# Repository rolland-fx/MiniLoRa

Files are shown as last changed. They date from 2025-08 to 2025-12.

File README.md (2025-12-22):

# Introduction

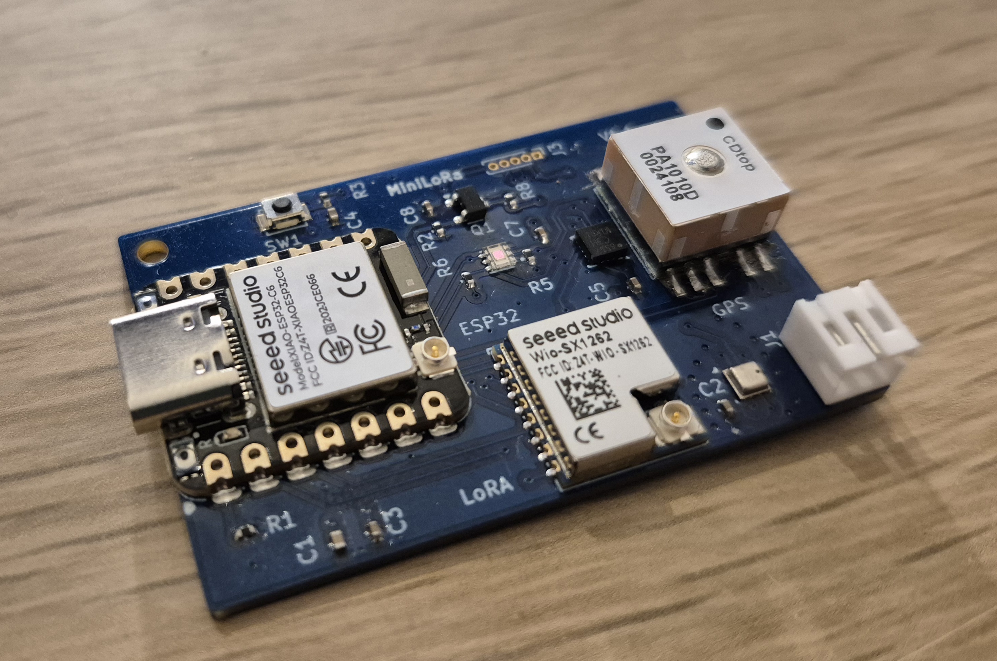
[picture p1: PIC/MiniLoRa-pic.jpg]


---
<!---
Discord server dedicated to this project :
<a href="https://discord.gg/ZdWrauP4Yt"><img alt="Discord" src="https://img.shields.io/badge/-Join-lightblue?logo=discord"></a>
---
-->
## Table of Contents

- [✨ What's MiniLoRa?](#-whats-MiniLoRa)
- [⚙️ Hardware Overview](#-hardware-overview)
- [💾 Software Overview](#-software-overview)
- [🚀To Do and Next Steps](#-to-do-and-next-steps)

## ✨ What's MiniLoRa?

Small size multi-purpose **ESP32-C6** board with **LoRa** and **2.4 GHz** connectivity.

**Main focus**

* Low power consumption for long battery life
* Multiple wireless connectivity
* Sensors packed
* Small size

### Features

* ESP32-C6 -> <a href="./DOC/Datasheets/esp32-c6.pdf">XIAO-ESP32C6</a>
  * 32 bits RISC-V Main processor : 160 MHz
  * 32 bits RISC-V Low power processor : 20 MHz
  * 512 KB RAM
  * 4 MB FLASH
  * RTC
  * Wi-Fi 6 (2.4 GHz)
  * Bluetooth 5 (BLE)
  * Zigbee / Matter / Thread (802.15.4)
  * All 2.4 GHz radios : Internal or external antenna switch via GPIO
* LoRa modem -> <a href="./DOC/Datasheets/Wio-SX1262_Module.pdf">WIO-SX1262</a>
  * LoRaWan capable
  * External Antenna
* GNSS with integrated antenna and PPS -> <a href="./DOC/Datasheets/CD-PA1010D.pdf">CD-PA1010D</a>
* Temperature, humidity and pressure sensor -> <a href="./DOC/Datasheets/bst-bme280-ds002.pdf">BME280</a>
* Luminosity sensor -> <a href="./DOC/Datasheets/opt3001.pdf">OPT3001</a>
* 3-axis accelerometer -> <a href="./DOC/Datasheets/lis3dh.pdf">LIS3DH</a>
* External connector with : Power, I2C and 1 GPIO
* 1 user accessible LED
* 1 user accessible button
* Voltage reading of the battery
* Integrated BMS and JST connector

## ⚙️ Hardware Overview

**PCB dimension**

| D| mm|
| --- | --- |
| L | 50 |
| W | 32 |
| H | 12,5* |

* including GNSS module and JST connector

**PCB Info**

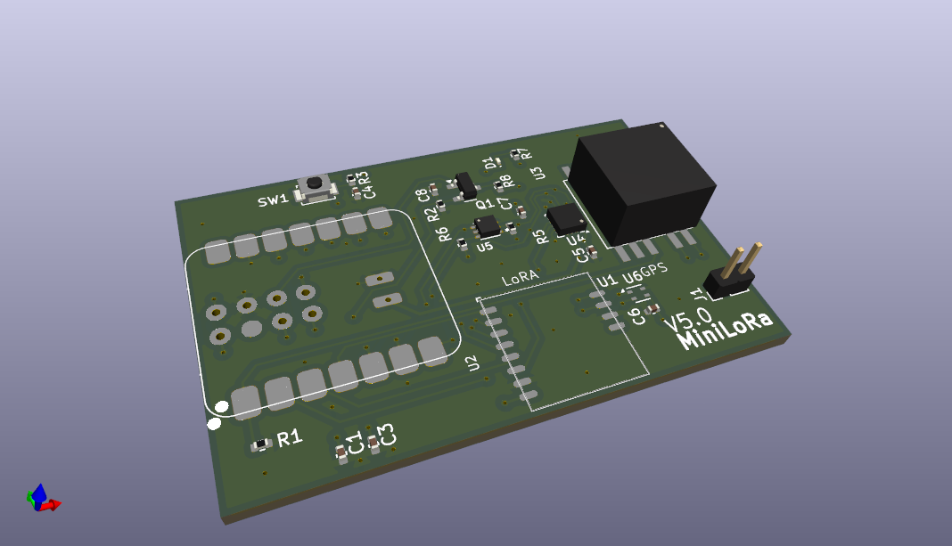
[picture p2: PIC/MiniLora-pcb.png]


Design with Kicad 9.0

* Full schematic and design can be found under **HW\PCB**
* Production files for the current batch are also included
* Libraries used can be found under **HW\PCB\lib**
* PDF can be found under : **DOC\Schematics**

**Enclosure Info**

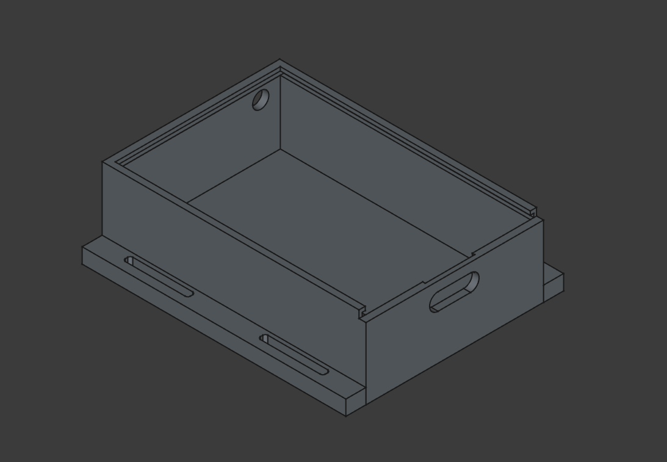
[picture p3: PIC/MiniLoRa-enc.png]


Design with FreeCad 1.0

* Very basic and not finished
* Can be 3D printed with basic HW
* Should be improved in the future
* Thought to be attached to backpack

## 💾 Software Overview

I2C adresses of sensors

| Sensor| ADD|
| --- | --- |
| GNSS | 0x10 |
| ACC | 0x18 |
| TEMP | 0x76 |
| LUM | 0x47 |

GPIO Mapping

| GPIO| Usage| Usable in SW ? | ADC ? | LP GPIO ?| Note|
| --- | --- | --- | --- | --- |---|
| 0 | WakeUp GNSS | X | X | X | |
| 1 | LoRa Busy + ACC Interupt | X | X | X | Mixed both signal|
| 2 | LoRa Reset | X | X | X | |
| 3 | 2.4 GHz switch EN | X | X | X | |
| 4 | Bat. Reading En. + External GPIO  | X | X | X | Use to activate External GPIO and EN. Bat reading |
| 5 | Bat. Analog  | X |X | X | Read Vbat/2 when active |
| 6 | PPS | X | X | X | |
| 7 | User Button | X |  | X | |
| 8 | Not available on XIAO ESP32C6 Module| | | | Strapping pin, HW pull-UP |
| 9 | Boot| | | | |
| 10-11 | N/A on ESP32C6 with Inc. FLASH| | | | |
| 12 | USB DN| | | | Used for serial and prog. |
| 13 | USB DP| | | | Used for serial and prog. |
| 14 | 2.4GHz switch Select| X | | | |
| 15 | Orange LED| X | | | |
| 16 | LoRa DIO1 | X | | | |
| 17 | LoRa SPI Select | X | | | |
| 18 | SPI MOSI | X | | | |
| 19 | SPI SCK | X | | | |
| 20 | SPI MISO | X | | | |
| 21 | LoRa RF Switch | X | | |Actually useless. GPIO will be reused in next version |
| 22 | I2C SDA | X | | | |
| 23 | i2C SPI | X | | | |
| 24 - 30| Internal SPI FLASH | | | | Not exposed|

External Connector Mapping

1 is defined as the squared one, closest to J3 marking 

| Pin | Usage|
| --- | --- |
| 1 | GND |
| 2 | SCL |
| 3 | SDA |
| 4 | VCC |
| 5 | GPIO6 |

## 🚀To Do and Next Steps

Here are the idea for the next improvement and developpement :

### Software

* Create a first full version in Arduino : Mostly done.
* Architecture
  * Create a core with FreeRTOS or Zephyr
  * Create drivers for all HW
  * File system for sys. files and data files
  * Init routine and deep sleep related routine
  * "1 Button, 1 LED" interface
* Possible SW usage
  * Very long battery life LoRaWAN tracker (all sensors) + reverse channel
  * NTP (GPS with PPS) Wi-Fi server
  * Indoor Zigbee / Wi-Fi / BLE sensor (all but GPS)  + reverse channel
  * Outdoor environmental sensor (all sensors)  + reverse channel
  * Outdoor offline sensor logging (Storage to FLASH)
  * Anti-theft device (interupt on Acc + all Radios)
* Other related SW
  * BLE App for configuration
  * USB-C (serial) App for configuration  

### Hardware

* Size can me optimized
* GNSS module with external flat antenna
* Replace JST 2.0 by PH1.25 for the Battery connector
* Replace External connector by 1.25mm pitch connector
  * GND + VCC
  * I2C
  * 2 GPIOs (probably one shared with another thing and one dedicated)   
* Better thermal isolation for BME280
* Sx1262 RF_SWITCH (GPIO 21) is not needed and can be used for something else.
* Replace XIAO module par self-made ESP32C6 module -> BIG WORK
  * Use ESP32-C6FH8 -> 8 MB of FLASH
  * Remove 2.4 GHz switch to get back 2 GPIO
  * GPIO 8 : could be used for an OUTPUT (to avoid strapping issue)
  * Replace BMS for solar cell use and faster charge : CN3165 or keeping the same, but change the cabling
  * Chose either chip antenna or external connector

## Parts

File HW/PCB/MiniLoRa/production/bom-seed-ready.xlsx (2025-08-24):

Designator | MPN/Seeed SKU | Qty | Link
D1 | 304090045 | 1
C5,C3,C7,C6,C8 | 302010004 | 5
SW1 | 311020679 | 1
R3,R5,R6,R1 | 301010004 | 4
U2 | 113991254 | 1
R8,R2 | 301010033 | 2
C4,C1 | 302010053 | 2
Q1 | 305031501 | 1
U5 | 314020321 | 1
R7 | 301010001 | 1
U6 | 314010719 | 1
U1 | 114993390 | 1 | https://www.seeedstudio.com/Wio-SX1262-Wireless-Module-p-5981.html
U4 | 314080105 | 1

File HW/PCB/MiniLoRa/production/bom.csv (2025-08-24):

Designator | Footprint | Quantity | Value | LCSC Part #
C1 | 0402 | 1 | 10u | C15525
C2 | 0402 | 1 | 1u | C14445
C3, C6, C7, C8 | 0402 | 4 | 0.1u | C1546
C4, C5 | 0402 | 2 | 10uF | C15525
D1, D2 | 0805 | 2 | LED | C2293
J1 | PinHeader_1x02_P2.00mm_Vertical | 1 | Conn_01x02
Q1 | SOT-23 | 1 | AO3400A | C20917
R1, R3, R5, R6, R9 | 0402 | 5 | 10K | C25744
R2, R8 | 0402 | 2 | 100k | C60491
R4, R7 | 0402 | 2 | 1.5k | C25867
SW1, SW2 | SW_SPST_B3U-1000P-B | 2 | SW_Push | C498294
U1 | wio-sx1262 | 1 | Wio-SX1262
U2 | XIAO-ESP32C6-SMD | 1 | XIAO-ESP32-S3-SMD
U3 | CDTop_MT3333_PA1010D | 1 | PA1010D
U5 | SON65P200X200X65-7N | 1 | OPT3001DNPR | C90462
U6 | Sensirion_DFN-4_1.5x1.5mm_P0.8mm_SHT4x_NoCentralPad | 1 | SHT4x | C7461852

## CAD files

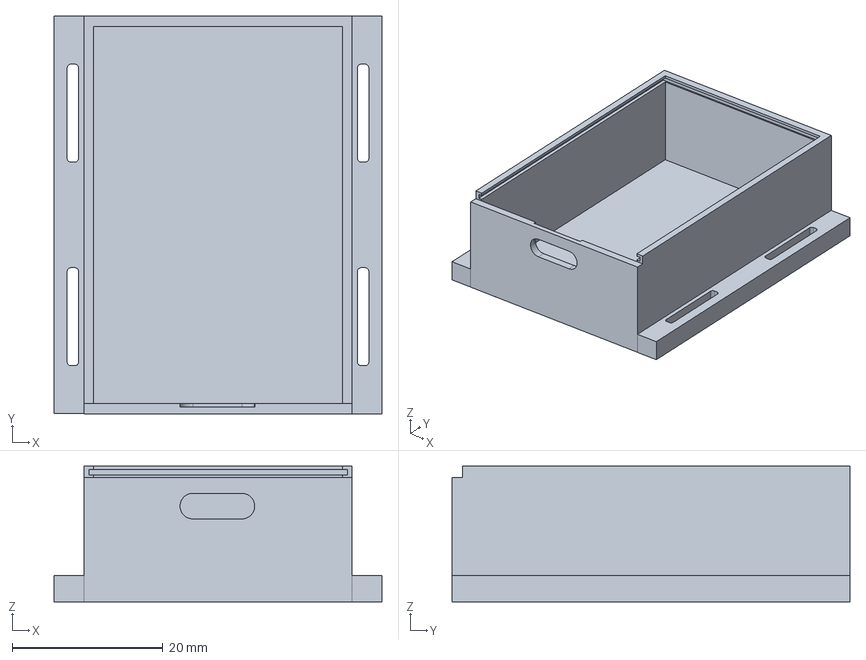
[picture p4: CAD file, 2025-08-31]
HW/Enclosure/MiniLoRa-Box.FCStd
43.5 x 52.8 x 18.0 mm

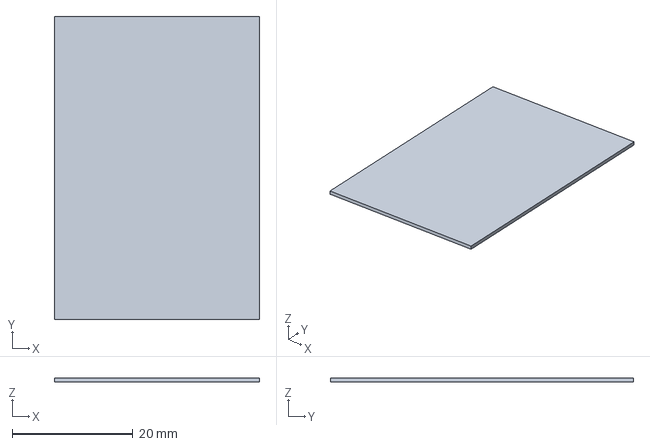
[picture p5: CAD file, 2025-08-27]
HW/Enclosure/MiniLoRa-Box-Top.3mf
34.0 x 50.2 x 0.7 mm

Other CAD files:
HW/Enclosure/MiniLoRa-Box-Body.3mf
HW/OLD-BETA5/Enclosure/MiniLoRa-Box-Body.3mf

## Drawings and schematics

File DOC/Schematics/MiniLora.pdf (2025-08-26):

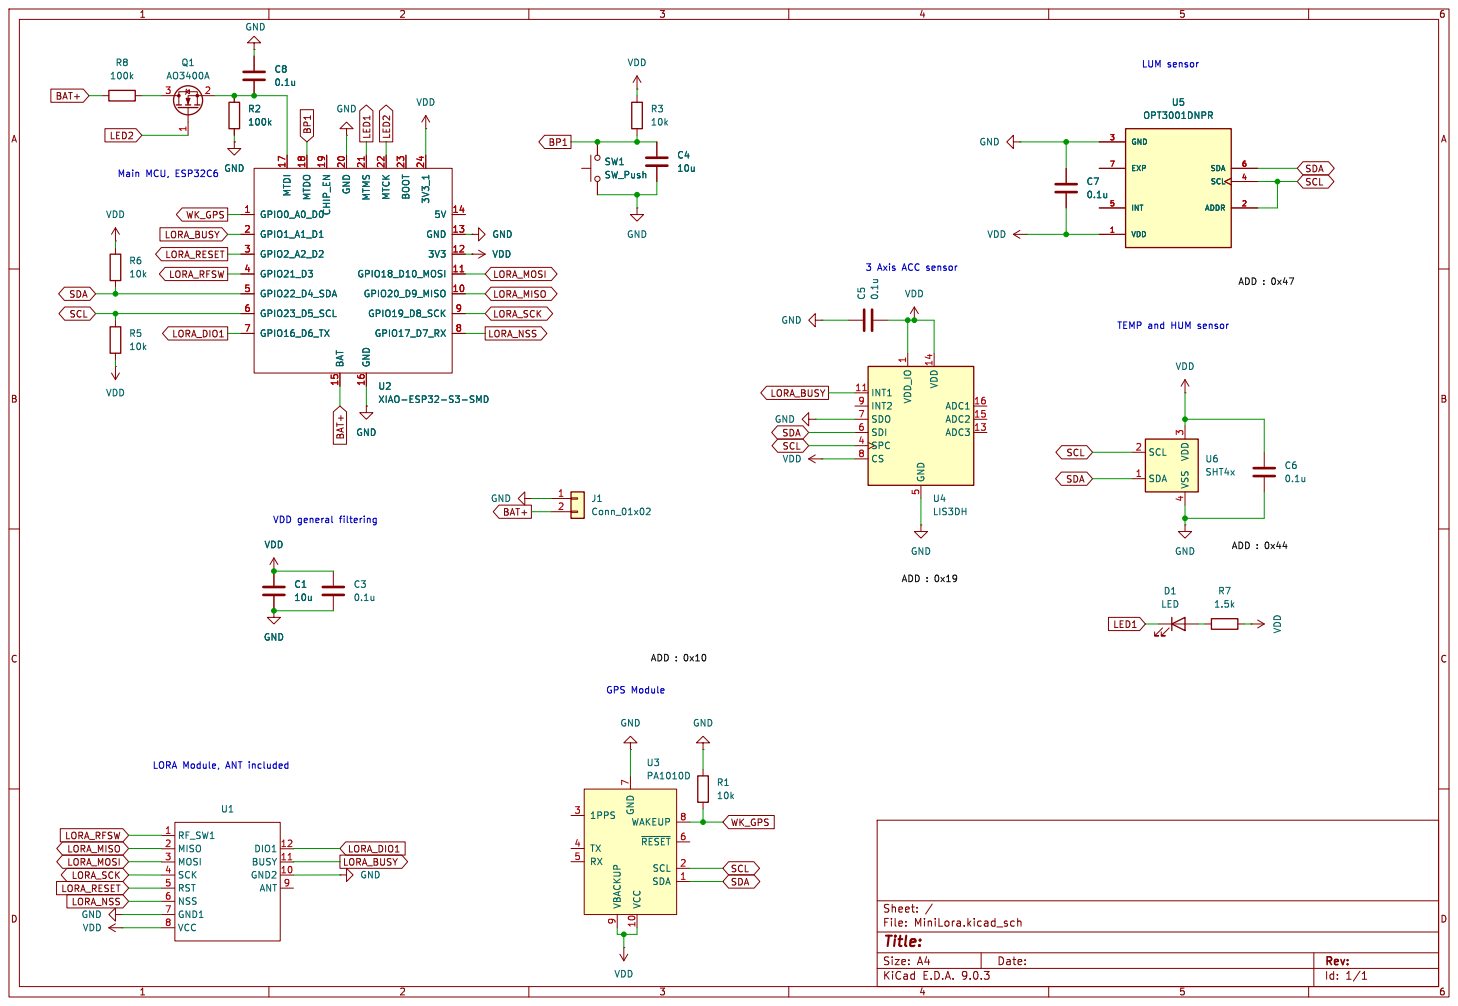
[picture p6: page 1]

LUM sensor TEMP and HUM sensor C1

ADD : 0x44 ADD : 0x47 ADD : 0x19 ADD : 0x10

Id: 1/1 Title: File: MiniLora.kicad_sch Sheet: / C1

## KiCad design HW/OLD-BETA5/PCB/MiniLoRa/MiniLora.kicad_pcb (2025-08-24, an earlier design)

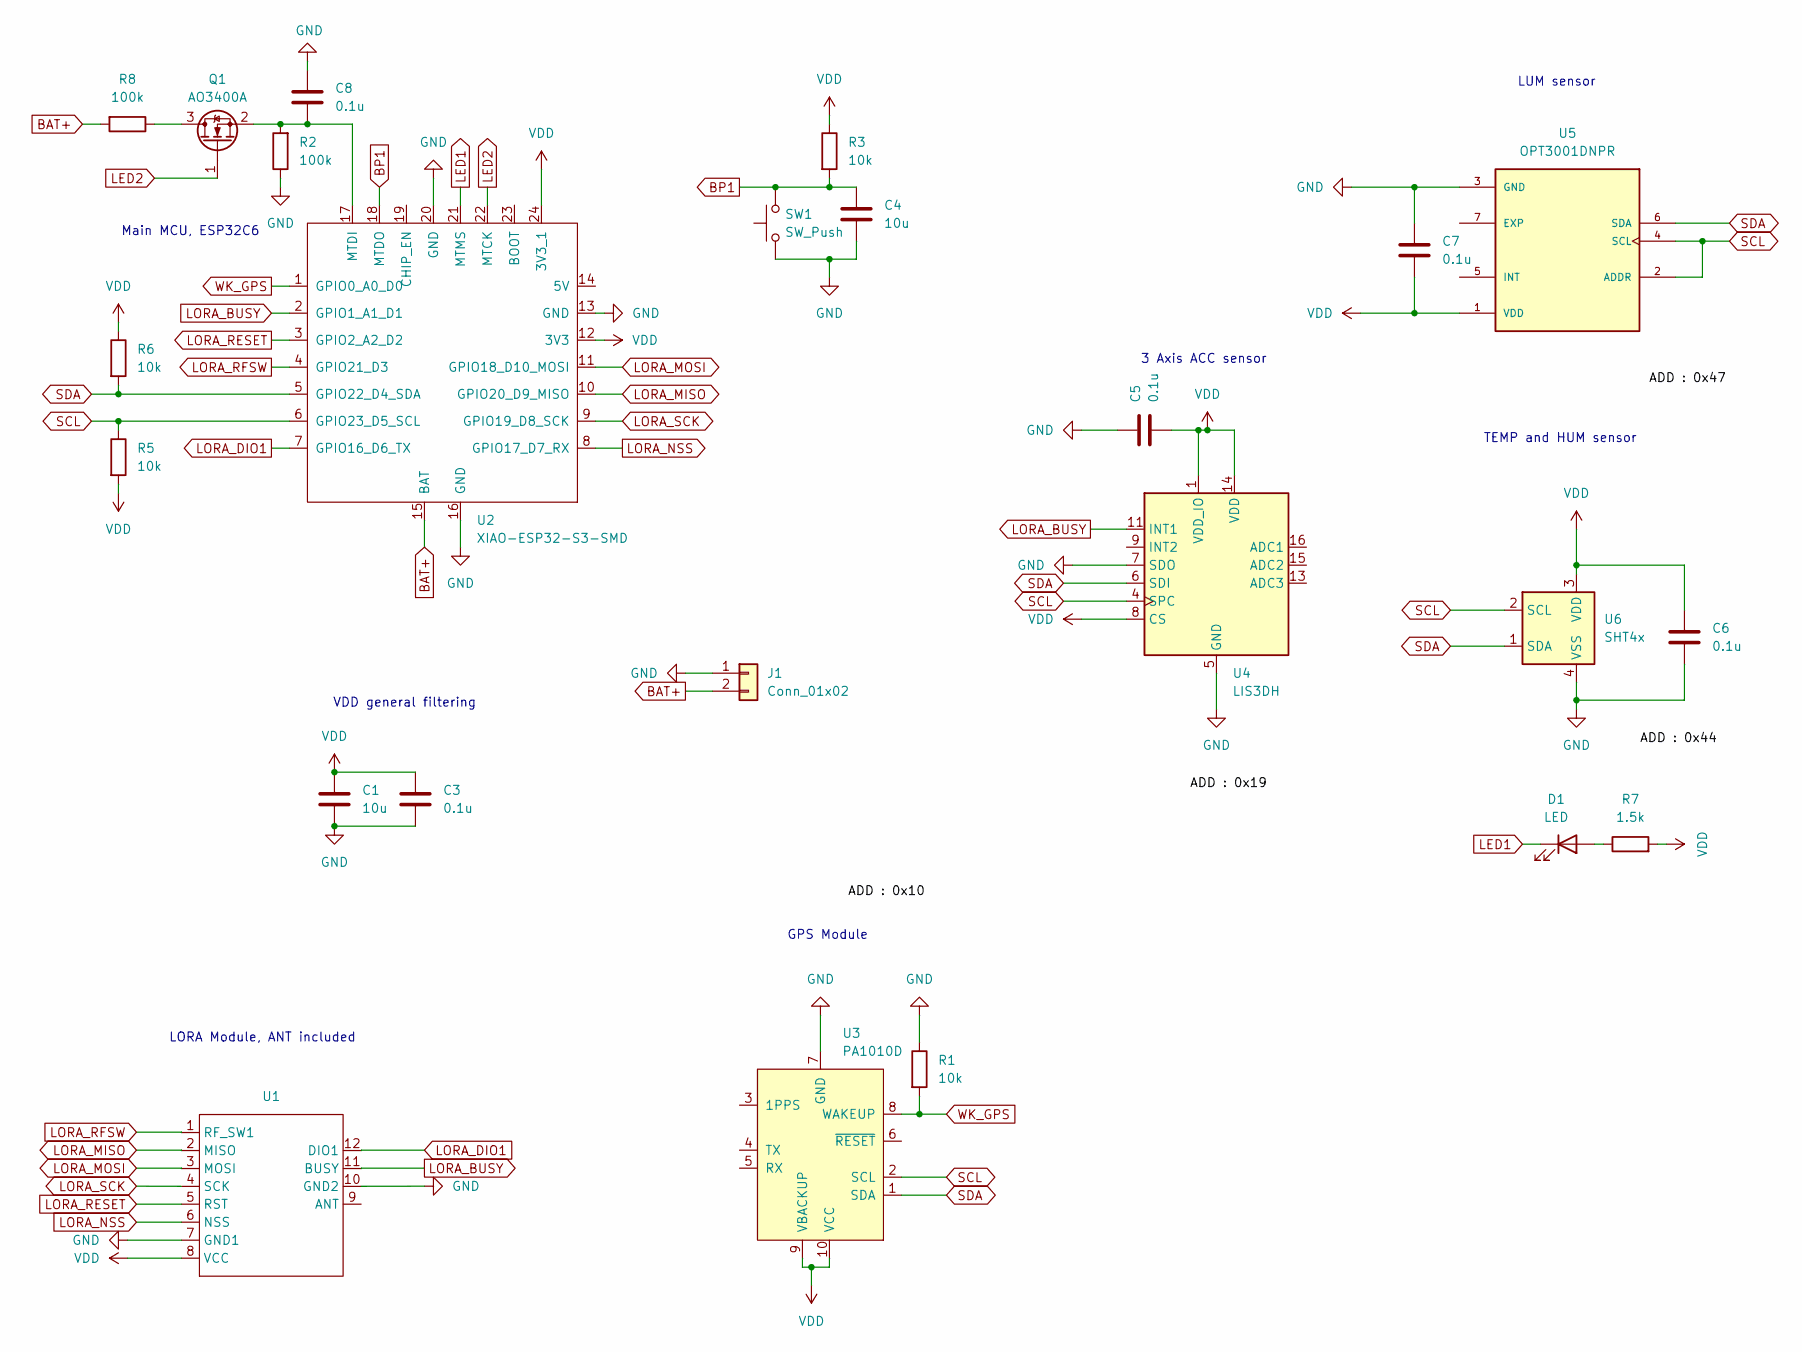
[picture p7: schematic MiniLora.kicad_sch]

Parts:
C1, C4: 10u; C_0402_1005Metric; LCSC PN C15525
C3, C5, C6, C7, C8: 0.1u; C_0402_1005Metric; LCSC PN C1546
D1: LED; LED_0201_0603Metric; LCSC PN C2293
J1: Conn_01x02; PinHeader_1x02_P2.00mm_Vertical
Q1: AO3400A; SOT-23; LCSC PN C20917
R1: 10k; R_0402_1005Metric; LCSC PN C25765
R2, R8: 100k; R_0402_1005Metric; LCSC PN C60491
R3, R5, R6: 10k; R_0402_1005Metric; LCSC PN C25744
R7: 1.5k; R_0402_1005Metric; LCSC PN C25867
SW1: SW_Push; SW_SPST_B3U-1000P-B; LCSC PN C498294
U1: Wio-SX1262; wio-sx1262
U2: XIAO-ESP32-S3-SMD; XIAO-ESP32C6-SMD
U3: PA1010D; CDTop_MT3333_PA1010D
U4: LIS3DH; LGA-16_3x3mm_P0.5mm_LayoutBorder3x5y
U5: OPT3001DNPR; SON65P200X200X65-7N; PARTREV 01/2018; LCSC PN C90462
U6: SHT4x; Sensirion_DFN-4_1.5x1.5mm_P0.8mm_SHT4x_NoCentralPad; LCSC PN C7461852

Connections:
BAT+: J1.2, R8.2, U2.15 (BAT)
BP1: C4.1, R3.2, SW1.2, U2.18 (MTDO)
GND: C1.2, C3.2, C4.2, C5.1, C6.2, C7.1, C8.1, J1.1, R1.1, R2.1, SW1.1, U1.7 (GND1), U1.10 (GND2), U2.13 (GND), U2.16 (GND), U2.20 (GND), U3.7 (GND), U4.5 (GND), U4.7 (SDO), U4.10 (GND), U4.12 (GND), U5.3 (GND), U6.4 (VSS)
LED1: D1.1 (K), U2.21 (MTMS)
LED2: Q1.1 (G), U2.22 (MTCK)
LORA_BUSY: U1.11 (BUSY), U2.2 (GPIO1_A1_D1), U4.11 (INT1)
LORA_DIO1: U1.12 (DIO1), U2.7 (GPIO16_D6_TX)
LORA_MISO: U1.2 (MISO), U2.10 (GPIO20_D9_MISO)
LORA_MOSI: U1.3 (MOSI), U2.11 (GPIO18_D10_MOSI)
LORA_NSS: U1.6 (NSS), U2.8 (GPIO17_D7_RX)
LORA_RESET: U1.5 (RST), U2.3 (GPIO2_A2_D2)
LORA_RFSW: U1.1 (RF_SW1), U2.4 (GPIO21_D3)
LORA_SCK: U1.4 (SCK), U2.9 (GPIO19_D8_SCK)
unnamed: D1.2 (A), R7.1
unnamed: Q1.3 (D), R8.1
unnamed: C8.2, Q1.2 (S), R2.2, U2.17 (MTDI)
SCL: R5.1, U2.6 (GPIO23_D5_SCL), U3.2 (SCL), U4.4 (SPC), U5.2 (ADDR), U5.4 (SCL), U6.2 (SCL)
SDA: R6.2, U2.5 (GPIO22_D4_SDA), U3.1 (SDA), U4.6 (SDI), U5.6 (SDA), U6.1 (SDA)
VDD: C1.1, C3.1, C5.2, C6.1, C7.2, R3.1, R5.2, R6.1, R7.2, U1.8 (VCC), U2.12 (3V3), U2.24 (3V3_1), U3.9 (VBACKUP), U3.10 (VCC), U4.1 (VDD_IO), U4.8 (CS), U4.14 (VDD), U5.1 (VDD), U6.3 (VDD)
WK_GPS: R1.2, U2.1 (GPIO0_A0_D0), U3.8 (WAKEUP)

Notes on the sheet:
LUM sensor
TEMP and HUM sensor
LORA Module, ANT included
3 Axis ACC sensor
Main MCU, ESP32C6
GPS Module
VDD general filtering

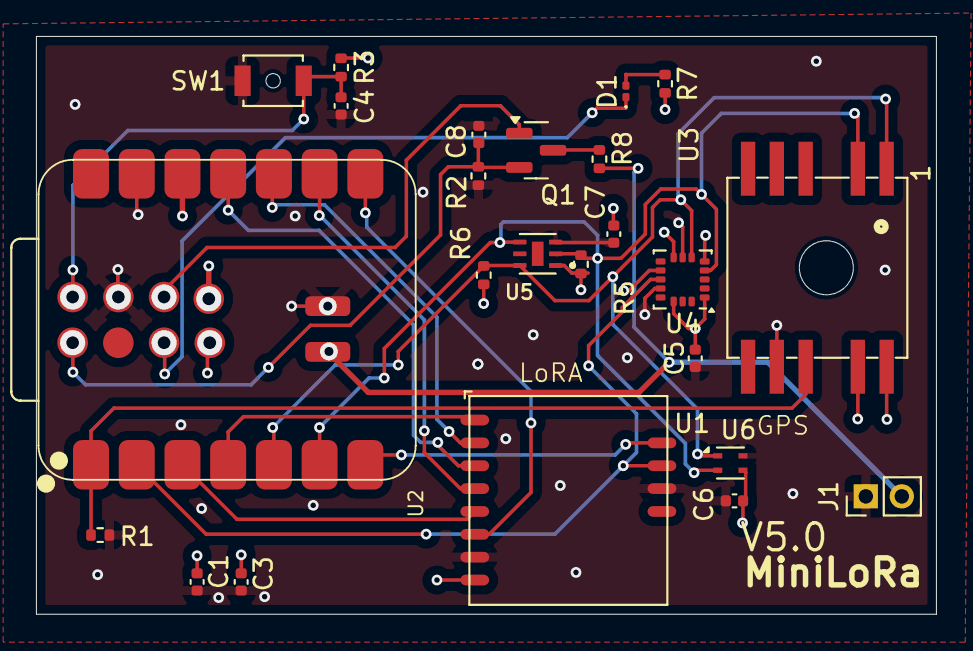
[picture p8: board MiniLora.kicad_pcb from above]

Board: 4 copper layers, 50.0 x 32.1 mm, 24 parts (0 on the bottom side), 20 nets.

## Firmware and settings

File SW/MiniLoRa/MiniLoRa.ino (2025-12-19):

#include <Wire.h>
#include <Adafruit_LIS3DH.h>
#include <Adafruit_Sensor.h>
#include <Arduino.h>
#include <SensirionI2cSht4x.h>
#include "SparkFun_I2C_GPS_Arduino_Library.h"
//#include <BLEDevice.h>
//#include <BLEUtils.h>
//#include <BLEServer.h>
#include <TinyGPSPlus.h>
#include <SensirionI2cSht4x.h>
#include <BME280_Arduino_I2C.h>

#include "soc/soc_caps.h"
#include "esp_sleep.h"
#include "Arduino.h"
#include "esp_timer.h"
#include "driver/rtc_io.h"
#include "soc/rtc.h"
#include "driver/gpio.h"
#include <ESP32Time.h>
#include <ByteConvert.hpp>

#include "config.h"

#define DEBUG true
#define uS_TO_mS_FACTOR 1000ULL


#define RANGE 1
int const SLEEP_T[6] = { 60000, 300000, 600000, 900000, 1200000, 1800000};

#define WIFI false
#define BLE false
#define ZIGBEE false
#define LORAWAN false
#define LOCAL_STORE false

#define GNSS true
#define SHT40 false // all SHT40 is present for previous proto. Will be removed ASAP
#define BME280 true
#define OPT30 true
#define LIS3DH true // for now, cause issue with the SPI for LoRa. Will be fixed later. Due to the library used

const gpio_num_t LORA_RST = GPIO_NUM_2;
const gpio_num_t GNSS_RST = GPIO_NUM_0;
const gpio_num_t LED_ORANGE = GPIO_NUM_15;
const gpio_num_t BUTTON = GPIO_NUM_7;
const gpio_num_t BAT_ON = GPIO_NUM_4;
const gpio_num_t BAT_LV = GPIO_NUM_5;
const gpio_num_t PPS = GPIO_NUM_6;
const gpio_num_t EXT_GPIO = GPIO_NUM_4;
const gpio_num_t INT_ACC = GPIO_NUM_1;

struct Data { //Total size : 57 bytes. To Store data with all the precisions
  int8_t Temp;
  uint8_t Hum;
  uint16_t Pres;
  uint16_t Bat_vol;
  uint16_t Lum;
  uint16_t Acc_x;
  uint16_t Acc_y;
  uint16_t Acc_z;
  double Lat;
  double Lon;
  int16_t Alt;
  uint8_t Sat;
  uint32_t Time;
  char UTC[20];
};

struct LoRaWanData { //Total size : 25 bytes. To send via LoRaWan
  int8_t Temp;
  uint8_t Hum;
  uint8_t Pres;
  uint8_t Bat_vol;
  uint16_t Lum;
  uint8_t Acc_x;
  uint8_t Acc_y;
  uint8_t Acc_z;
  int32_t Lat;
  int32_t Lon;
  int16_t Alt;
  uint8_t Sat;
  uint32_t Time;
};


char* GNSS_DEEP_SLEEP = "$PMTK225,4*2F\r\n";
char* GNSS_MID_POWER = "$PMTK220,200*2C\r\n";

SensirionI2cSht4x sensor;
Adafruit_LIS3DH lis = Adafruit_LIS3DH();
Data LiveData;
LoRaWanData LoRaData;
float fTemp;
float fHum;

ESP32Time rtc;

uint8_t buf[4];
uint8_t uplinkPayload[23];

double Lat_buffer;
double Lon_buffer;


uint16_t Lum_man;
uint16_t Lum_exp;
TinyGPSPlus gps;
I2CGPS myI2CGPS;
BME280_Arduino_I2C bme;

esp_sleep_wakeup_cause_t wakeup_reason;


#define BUTTON_PIN_BITMASK(GPIO) (1ULL << GPIO)  // 2 ^ GPIO_NUMBER in hex
#define WAKEUP_GPIO              GPIO_NUM_7     // Only RTC IO are allowed - ESP32 Pin example

void setup() {
  // Wake-up procedure
  pinMode(LORA_RST, OUTPUT);
  pinMode(GNSS_RST, OUTPUT);
  pinMode(LED_ORANGE, OUTPUT);
  pinMode(BAT_ON, OUTPUT);
  pinMode(BAT_LV, INPUT);
  digitalWrite(LORA_RST, LOW);
  digitalWrite(LED_ORANGE, LOW);
  gpio_hold_dis(LED_ORANGE);
  gpio_hold_dis(GNSS_RST);
  gpio_hold_dis(LORA_RST);
  gpio_hold_dis(BAT_ON);
    if (GNSS) {
    digitalWrite(GNSS_RST, HIGH);
    delay(100);
    }
  wakeup_reason = esp_sleep_get_wakeup_cause();
  if (DEBUG) {
    Serial.begin(115200);
    delay(100);
    Serial.println(wakeup_reason);
  }
  if(wakeup_reason == ESP_SLEEP_WAKEUP_EXT1)
  {
    delay(20000);
  }
  Wire.begin();
  if (GNSS) {
    Wire.beginTransmission(0x10);
    Wire.write((uint8_t*)GNSS_MID_POWER, 20);
    Wire.endTransmission();
  }
  if (SHT40) {
    sensor.begin(Wire, 0x44);
    sensor.softReset();
  }
  if (BME280){
    bme.begin();

  }
  if (OPT30) {
    Wire.beginTransmission(0x47);  // ADDR pulled to GND
    Wire.write(0x01);              // config register
    Wire.write(0xCE);              // range, etc
    Wire.write(0x10);
    Wire.endTransmission();
    Wire.beginTransmission(0x47);
    Wire.write(0);           // result register
    Wire.endTransmission();  // sends a STOP
  }
  if (LIS3DH) {
    lis.begin(0x18);
    lis.setRange(LIS3DH_RANGE_4_G);
    lis.setPerformanceMode(LIS3DH_MODE_LOW_POWER);
    lis.setDataRate(LIS3DH_DATARATE_10_HZ);
    Wire.endTransmission();
  }
  if (LORAWAN) {
    digitalWrite(LORA_RST, HIGH);
  }
  if (LOCAL_STORE) {
  }
  delay(250);
  delay(2250);
  // Data acquisition
  if (GNSS) {
    uint8_t turn = 0;
    myI2CGPS.begin();
    delay(500);
    while ((!gps.location.isValid()) || (turn < 5) || (gps.satellites.value() <= 6))
    {
       while (myI2CGPS.available() )  //available() returns the number of new bytes available from the GPS module
      {
        gps.encode(myI2CGPS.read());  //Feed the GPS parser
      }
      if (gps.time.isUpdated())  //Check to see if new GPS info is available
     {
        if (gps.time.isValid() && gps.location.isValid()) {
          LiveData.Lon = gps.location.lng();
          LiveData.Lat = gps.location.lat();
          if (gps.altitude.meters() > 32767) LiveData.Alt = 0;
          else LiveData.Alt = (int16_t)gps.altitude.meters();
          LiveData.Sat = gps.satellites.value();
          rtc.setTime(gps.time.second(), gps.time.minute(), gps.time.hour(), gps.date.day(), gps.date.month(), gps.date.year());
          sprintf(LiveData.UTC,"%4d-%02d-%02dT%02d:%02d:%02dZ",gps.date.year(),gps.date.month(),gps.date.day(),gps.time.hour(),gps.time.minute(),gps.time.second());
          LiveData.Time = rtc.getEpoch();
        } 
     }
     delay(2500);
     if (DEBUG) {
        Serial.print("Satellites : ");
        Serial.println(gps.satellites.value());
     }
     turn++;
    }
  }
  if (SHT40) {
    sensor.measureMediumPrecision(fTemp, fHum);
    Wire.endTransmission();
    LiveData.Temp = (int)fTemp;
    LiveData.Hum = (int)fHum;
  }
  if (BME280){
    BME280Data* BMEdata = bme.read();
    LiveData.Temp = (int8_t)BMEdata->temperature;
    LiveData.Hum = (uint8_t)BMEdata->humidity;
    LiveData.Pres = (uint16_t)(BMEdata->pressure / 100);
  }
  if (OPT30) {
    Wire.requestFrom(0x47, 2);  // read 2 bytes from last address
    Wire.readBytes(buf, 2);
    Lum_exp = buf[0] >> 4;
    Lum_man = buf[1] | ((buf[0] & 0x0F) << 8);
    LiveData.Lum = (int)Lum_man * (0.01 * pow(2, Lum_exp));
    Wire.endTransmission();
  }
  if (LIS3DH) {
    lis.read();
    LiveData.Acc_x = (int)lis.x;
    LiveData.Acc_y = (int)lis.y;
    LiveData.Acc_z = (int)lis.z;
    Wire.endTransmission();
  }
  digitalWrite(BAT_ON, HIGH);
  delay(100);
  LiveData.Bat_vol = 2 * analogReadMilliVolts(BAT_LV);
  digitalWrite(BAT_ON, LOW);
  // Data storage // sending
  if (LORAWAN) {
    LoRaData.Temp = LiveData.Temp;
    LoRaData.Hum = LiveData.Hum;
    LoRaData.Pres = (uint8_t)(LiveData.Pres - 800); 
    LoRaData.Bat_vol = (uint8_t) map(LiveData.Bat_vol, 2500, 4300, 0, 255);
    LoRaData.Lum = LiveData.Lum;
    LoRaData.Acc_x = (uint8_t) map(LiveData.Acc_x, 0, 10000, 0, 255);
    LoRaData.Acc_y = (uint8_t) map(LiveData.Acc_y, 0, 10000, 0, 255);
    LoRaData.Acc_z = (uint8_t) map(LiveData.Acc_z, 0, 10000, 0, 255);
    Lat_buffer = LiveData.Lat* 1000000.0;
    Lon_buffer =  LiveData.Lon* 1000000.0;
    LoRaData.Lat = (int32_t)Lat_buffer;
    LoRaData.Lon = (int32_t)Lon_buffer; 
    LoRaData.Alt = LiveData.Alt;
    LoRaData.Sat = LiveData.Sat;
    LoRaData.Time = LiveData.Time;
    
    SPI.begin(SX1262_SCK, SX1262_MISO, SX1262_MOSI, SX1262_CS);
    delay(50);
    size_t s_lat = 0;
    size_t s_lon = 0;
    size_t s_time = 0;    
    int16_t state = radio.begin();
    Serial.print("Begin : ");
    Serial.println(stateDecode(state));
    state = node.beginOTAA(joinEUI, devEUI, nwkKey, appKey);
    Serial.print("OTAA Start : ");
    Serial.println(stateDecode(state));
    state = node.activateOTAA();
    Serial.print("OTAA Next : ");
    Serial.println(stateDecode(state));
    uplinkPayload[0] = LoRaData.Temp;
    uplinkPayload[1] = LoRaData.Hum;
    uplinkPayload[2] = LoRaData.Bat_vol;
    uplinkPayload[3] = lowByte(LoRaData.Lum);
    uplinkPayload[4] = highByte(LoRaData.Lum);  
    uplinkPayload[5] = LoRaData.Acc_x;
    uplinkPayload[6] = LoRaData.Acc_y;
    uplinkPayload[7] = LoRaData.Acc_z;
    uint8_t *a_lat = ByteConvert::varToArray<int>(s_lat,LoRaData.Lat);
    uplinkPayload[8] = a_lat[3];
    uplinkPayload[9] = a_lat[2];
    uplinkPayload[10] = a_lat[1];
    uplinkPayload[11] = a_lat[0];
    uint8_t *a_lon = ByteConvert::varToArray<int>(s_lon,LoRaData.Lon);     
    uplinkPayload[12] = a_lon[3];      
    uplinkPayload[13] = a_lon[2];       
    uplinkPayload[14] = a_lon[1];  
    uplinkPayload[15] = a_lon[0];  
    uplinkPayload[16] = lowByte(LoRaData.Alt);
    uplinkPayload[17] = highByte(LoRaData.Alt);
    uplinkPayload[18] = LoRaData.Sat;
    uint8_t *a_time = ByteConvert::varToArray<int>(s_time,LoRaData.Time);
    uplinkPayload[19] = a_time[3]; 
    uplinkPayload[20] = a_time[2]; 
    uplinkPayload[21] = a_time[1]; 
    uplinkPayload[22] = a_time[0]; 
    state = node.sendReceive(uplinkPayload, sizeof(uplinkPayload));
    Serial.print("Data Sending : ");
    Serial.println(stateDecode(state)); 
  }
  if (LOCAL_STORE) {
  }
  if (DEBUG) {
    Serial.print("<");
    Serial.print(LiveData.UTC);
    Serial.print(",");
    Serial.print(LiveData.Lat, 6);
    Serial.print(",");
    Serial.print(LiveData.Lon, 6);
    Serial.print(",");
    Serial.print(LiveData.Alt);
    Serial.print(",");
    Serial.print(LiveData.Sat);   
    Serial.print(",");
    Serial.print(LiveData.Temp);
    Serial.print(",");
    Serial.print(LiveData.Hum);
    Serial.print(",");
    Serial.print(LiveData.Pres);
    Serial.print(",");
    Serial.print(LiveData.Lum);
    Serial.print(",");
    Serial.print(LiveData.Acc_x);
    Serial.print(",");
    Serial.print(LiveData.Acc_y);
    Serial.print(",");
    Serial.print(LiveData.Acc_z);
    Serial.print(",");
    Serial.print(LiveData.Bat_vol);
    Serial.print(">");
    Serial.print("\n");
  }
  // Prepare for sleep
  esp_sleep_enable_timer_wakeup(SLEEP_T[RANGE] * uS_TO_mS_FACTOR);
  if (GNSS) {
    Wire.beginTransmission(0x10);
    Wire.write((uint8_t*)GNSS_DEEP_SLEEP, 17);
    Wire.endTransmission();
    digitalWrite(GNSS_RST, LOW);
  }
  if (SHT40) {
  }
  if (OPT30) {
  }
  if (LIS3DH) {
    lis.setDataRate(LIS3DH_DATARATE_POWERDOWN);
  }
  if (LORAWAN) {
    digitalWrite(LORA_RST, LOW);
  }
  if (LOCAL_STORE) {
  }
  if (DEBUG) {
    Serial.flush();
  }
  esp_sleep_enable_ext1_wakeup_io(BUTTON_PIN_BITMASK(WAKEUP_GPIO), ESP_EXT1_WAKEUP_ANY_LOW);
  rtc_gpio_pulldown_dis(WAKEUP_GPIO);  // GPIO33 is tie to GND in order to wake up in HIGH
  rtc_gpio_pullup_dis(WAKEUP_GPIO);   // Disable PULL_UP in order to allow it to wakeup on HIGH

  gpio_hold_en(GNSS_RST);
  gpio_hold_en(LORA_RST);
  digitalWrite(LED_ORANGE, HIGH);
  gpio_hold_en(LED_ORANGE);
  gpio_hold_en(BAT_ON);
  esp_deep_sleep_start();
}

void loop() {
}

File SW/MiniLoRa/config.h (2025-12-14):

#ifndef _RADIOLIB_EX_LORAWAN_CONFIG_H
#define _RADIOLIB_EX_LORAWAN_CONFIG_H

#include <RadioLib.h>
#include <SPI.h>
// first you have to set your radio model and pin configuration
// this is provided just as a default example
#define SX1262_CS GPIO_NUM_17
#define SX1262_SCK GPIO_NUM_19
#define SX1262_MOSI GPIO_NUM_18
#define SX1262_MISO GPIO_NUM_20
#define SX1262_RESET GPIO_NUM_2
#define SX1262_BUSY GPIO_NUM_1
#define SX1262_DIO1 GPIO_NUM_16

SX1262 radio = new Module(SX1262_CS, SX1262_DIO1, SX1262_RESET, SX1262_BUSY);


// joinEUI - previous versions of LoRaWAN called this AppEUI
// for development purposes you can use all zeros - see wiki for details
#define RADIOLIB_LORAWAN_JOIN_EUI  0x0000000000000000

// the Device EUI & two keys can be generated on the TTN console 
#ifndef RADIOLIB_LORAWAN_DEV_EUI   // Replace with your Device EUI
#define RADIOLIB_LORAWAN_DEV_EUI   0x0000000000000000
#endif
#ifndef RADIOLIB_LORAWAN_APP_KEY   // Replace with your App Key 
#define RADIOLIB_LORAWAN_APP_KEY   0x00, 0x00, 0x00, 0x00, 0x00, 0x00, 0x00, 0x00, 0x00, 0x00, 0x00, 0x00, 0x00, 0x00, 0x00, 0x00 
#endif
#ifndef RADIOLIB_LORAWAN_NWK_KEY   // Put your Nwk Key here
#define RADIOLIB_LORAWAN_NWK_KEY   0x00, 0x00, 0x00, 0x00, 0x00, 0x00, 0x00, 0x00, 0x00, 0x00, 0x00, 0x00, 0x00, 0x00, 0x00, 0x00
#endif

// for the curious, the #ifndef blocks allow for automated testing &/or you can
// put your EUI & keys in to your platformio.ini - see wiki for more tips

// regional choices: EU868, US915, AU915, AS923, AS923_2, AS923_3, AS923_4, IN865, KR920, CN470
const LoRaWANBand_t Region = EU868;

// subband choice: for US915/AU915 set to 2, for CN470 set to 1, otherwise leave on 0
const uint8_t subBand = 0;

// ============================================================================
// Below is to support the sketch - only make changes if the notes say so ...

// copy over the EUI's & keys in to the something that will not compile if incorrectly formatted
uint64_t joinEUI =   RADIOLIB_LORAWAN_JOIN_EUI;
uint64_t devEUI  =   RADIOLIB_LORAWAN_DEV_EUI;
uint8_t appKey[] = { RADIOLIB_LORAWAN_APP_KEY };
uint8_t nwkKey[] = { RADIOLIB_LORAWAN_NWK_KEY };

// create the LoRaWAN node
LoRaWANNode node(&radio, &Region, subBand);

// result code to text - these are error codes that can be raised when using LoRaWAN
// however, RadioLib has many more - see https://jgromes.github.io/RadioLib/group__status__codes.html for a complete list
String stateDecode(const int16_t result) {
  switch (result) {
  case RADIOLIB_ERR_NONE:
    return "ERR_NONE";
  case RADIOLIB_ERR_CHIP_NOT_FOUND:
    return "ERR_CHIP_NOT_FOUND";
  case RADIOLIB_ERR_PACKET_TOO_LONG:
    return "ERR_PACKET_TOO_LONG";
  case RADIOLIB_ERR_RX_TIMEOUT:
    return "ERR_RX_TIMEOUT";
  case RADIOLIB_ERR_MIC_MISMATCH:
    return "ERR_MIC_MISMATCH";
  case RADIOLIB_ERR_INVALID_BANDWIDTH:
    return "ERR_INVALID_BANDWIDTH";
  case RADIOLIB_ERR_INVALID_SPREADING_FACTOR:
    return "ERR_INVALID_SPREADING_FACTOR";
  case RADIOLIB_ERR_INVALID_CODING_RATE:
    return "ERR_INVALID_CODING_RATE";
  case RADIOLIB_ERR_INVALID_FREQUENCY:
    return "ERR_INVALID_FREQUENCY";
  case RADIOLIB_ERR_INVALID_OUTPUT_POWER:
    return "ERR_INVALID_OUTPUT_POWER";
  case RADIOLIB_ERR_NETWORK_NOT_JOINED:
	  return "RADIOLIB_ERR_NETWORK_NOT_JOINED";
  case RADIOLIB_ERR_DOWNLINK_MALFORMED:
    return "RADIOLIB_ERR_DOWNLINK_MALFORMED";
  case RADIOLIB_ERR_INVALID_REVISION:
    return "RADIOLIB_ERR_INVALID_REVISION";
  case RADIOLIB_ERR_INVALID_PORT:
    return "RADIOLIB_ERR_INVALID_PORT";
  case RADIOLIB_ERR_NO_RX_WINDOW:
    return "RADIOLIB_ERR_NO_RX_WINDOW";
  case RADIOLIB_ERR_INVALID_CID:
    return "RADIOLIB_ERR_INVALID_CID";
  case RADIOLIB_ERR_UPLINK_UNAVAILABLE:
    return "RADIOLIB_ERR_UPLINK_UNAVAILABLE";
  case RADIOLIB_ERR_COMMAND_QUEUE_FULL:
    return "RADIOLIB_ERR_COMMAND_QUEUE_FULL";
  case RADIOLIB_ERR_COMMAND_QUEUE_ITEM_NOT_FOUND:
    return "RADIOLIB_ERR_COMMAND_QUEUE_ITEM_NOT_FOUND";
  case RADIOLIB_ERR_JOIN_NONCE_INVALID:
    return "RADIOLIB_ERR_JOIN_NONCE_INVALID";
  case RADIOLIB_ERR_DWELL_TIME_EXCEEDED:
    return "RADIOLIB_ERR_DWELL_TIME_EXCEEDED";
  case RADIOLIB_ERR_CHECKSUM_MISMATCH:
    return "RADIOLIB_ERR_CHECKSUM_MISMATCH";
  case RADIOLIB_ERR_NO_JOIN_ACCEPT:
    return "RADIOLIB_ERR_NO_JOIN_ACCEPT";
  case RADIOLIB_LORAWAN_SESSION_RESTORED:
    return "RADIOLIB_LORAWAN_SESSION_RESTORED";
  case RADIOLIB_LORAWAN_NEW_SESSION:
    return "RADIOLIB_LORAWAN_NEW_SESSION";
  case RADIOLIB_ERR_NONCES_DISCARDED:
    return "RADIOLIB_ERR_NONCES_DISCARDED";
  case RADIOLIB_ERR_SESSION_DISCARDED:
    return "RADIOLIB_ERR_SESSION_DISCARDED";
  }
  return "See https://jgromes.github.io/RadioLib/group__status__codes.html";
}

// helper function to display a byte array
void arrayDump(uint8_t *buffer, uint16_t len) {
  for(uint16_t c = 0; c < len; c++) {
    char b = buffer[c];
    if(b < 0x10) { Serial.print('0'); }
    Serial.print(b, HEX);
  }
  Serial.println();
}

#endif

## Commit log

2025-08-24 Adding PCB and Enclosure
    [MiniLoRa-Box.3mf, MiniLoRa-Box.FCStd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]
2025-08-24 Adding MiniLoRa-PCBView and Picture
2025-08-26 adding pdf of schematic
2025-08-26 adding picture of enclosure
2025-08-27 new enclosure (still in progress)
    [MiniLoRa-Box-Body.3mf, MiniLoRa-Box-Top.3mf, MiniLoRa-Box.FCStd]
2025-08-31 1st ugly revision of SW
    [MiniLoRa-Box.3mf, Test-R5-Box.FCStd]
2025-08-31 Adding basic wakeup interrupt
2025-08-31 Enclosure updated
    [MiniLoRa-Box-Body.3mf, MiniLoRa-Box.FCStd, Test-R5-Box.FCStd]
2025-11-10 Backing-up Beta 5 for next release
    Here we go for the RC1
    [MiniLoRa-Box-Body.3mf, MiniLoRa-Box-Top.3mf, MiniLoRa-Box.FCStd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]
2025-12-19 updating lasted arduino code
